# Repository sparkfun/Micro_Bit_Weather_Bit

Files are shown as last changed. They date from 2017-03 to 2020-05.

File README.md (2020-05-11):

SparkFun weather:bit - micro:bit Carrier Board (Qwiic)
========================================

SparkFun weather:bit (https://www.sparkfun.com/products/15837)

[*SparkFun weather:bit (DEV-15837)*](https://www.sparkfun.com/products/15837)

The SparkFun weather:bit is a fully loaded “carrier” board for the micro:bit that, when combined with the micro:bit, provides you with a fully functional weather station. With the weather:bit you will have access to barometric pressure, relative humidity and temperature readings. There are also connections on this carrier board to optional sensors such as wind speed, direction, rain gauge and soil readings! The micro:bit has a lot of features and a lot of potential for weather data collection.

Repository Contents
-------------------

* **/Firmware** -  Example code used in the micro:climate Kit Experiment Guide. While they are compiled HEX codes, you can modify the example code once they are imported into MakeCode editor.
* **/Hardware** - Eagle design files (.brd, .sch)
* **/Production** - Production panel files (.brd)

Documentation
--------------
* **[Library](https://github.com/sparkfun/pxt-weather-bit)** - PXT weather:bit firmware
* **[micro:Climate Kit Experiment Guide](https://learn.sparkfun.com/tutorials/microclimate-kit-experiment-guide)** - Experiment guide using the weather:bit carrier board.
* **[Wireless Remote Weather Station with micro:bit](https://learn.sparkfun.com/tutorials/wireless-remote-weather-station-with-microbit/)** - Additional experiments for transmitting weather data wirelessly.

License Information
-------------------

This product is _**open source**_! 

Please review the LICENSE.md file for license information. 

If you have any questions or concerns on licensing, please contact technical support on our [SparkFun forums](https://forum.sparkfun.com/viewforum.php?f=152).

Distributed as-is; no warranty is given.

- Your friends at SparkFun.

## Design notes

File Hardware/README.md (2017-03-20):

SparkFun <PRODUCT NAME> Design Files
=====================================

The .sch and .brd files hare are Eagle CAD schematic and PCB design files from SparkFun Electronics.
A freeware version of Eagle can be found [here](http://www.cadsoftusa.com/download-eagle/freeware/).

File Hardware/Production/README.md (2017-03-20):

SparkFun <PRODUCT NAME> Production Files
=========================================

These are the production files SparkFun uses for printing PCBs.

License Information
-------------------
This product is open source! 

The hardware is released under [Creative Commons ShareAlike 4.0 International](https://creativecommons.org/licenses/by-sa/4.0/).

Please use, reuse, and modify these files as you see fit. Please maintain attribution to SparkFun Electronics and release anything derivative under the same license.

Distributed as-is; no warranty is given.

- Your friends at SparkFun.

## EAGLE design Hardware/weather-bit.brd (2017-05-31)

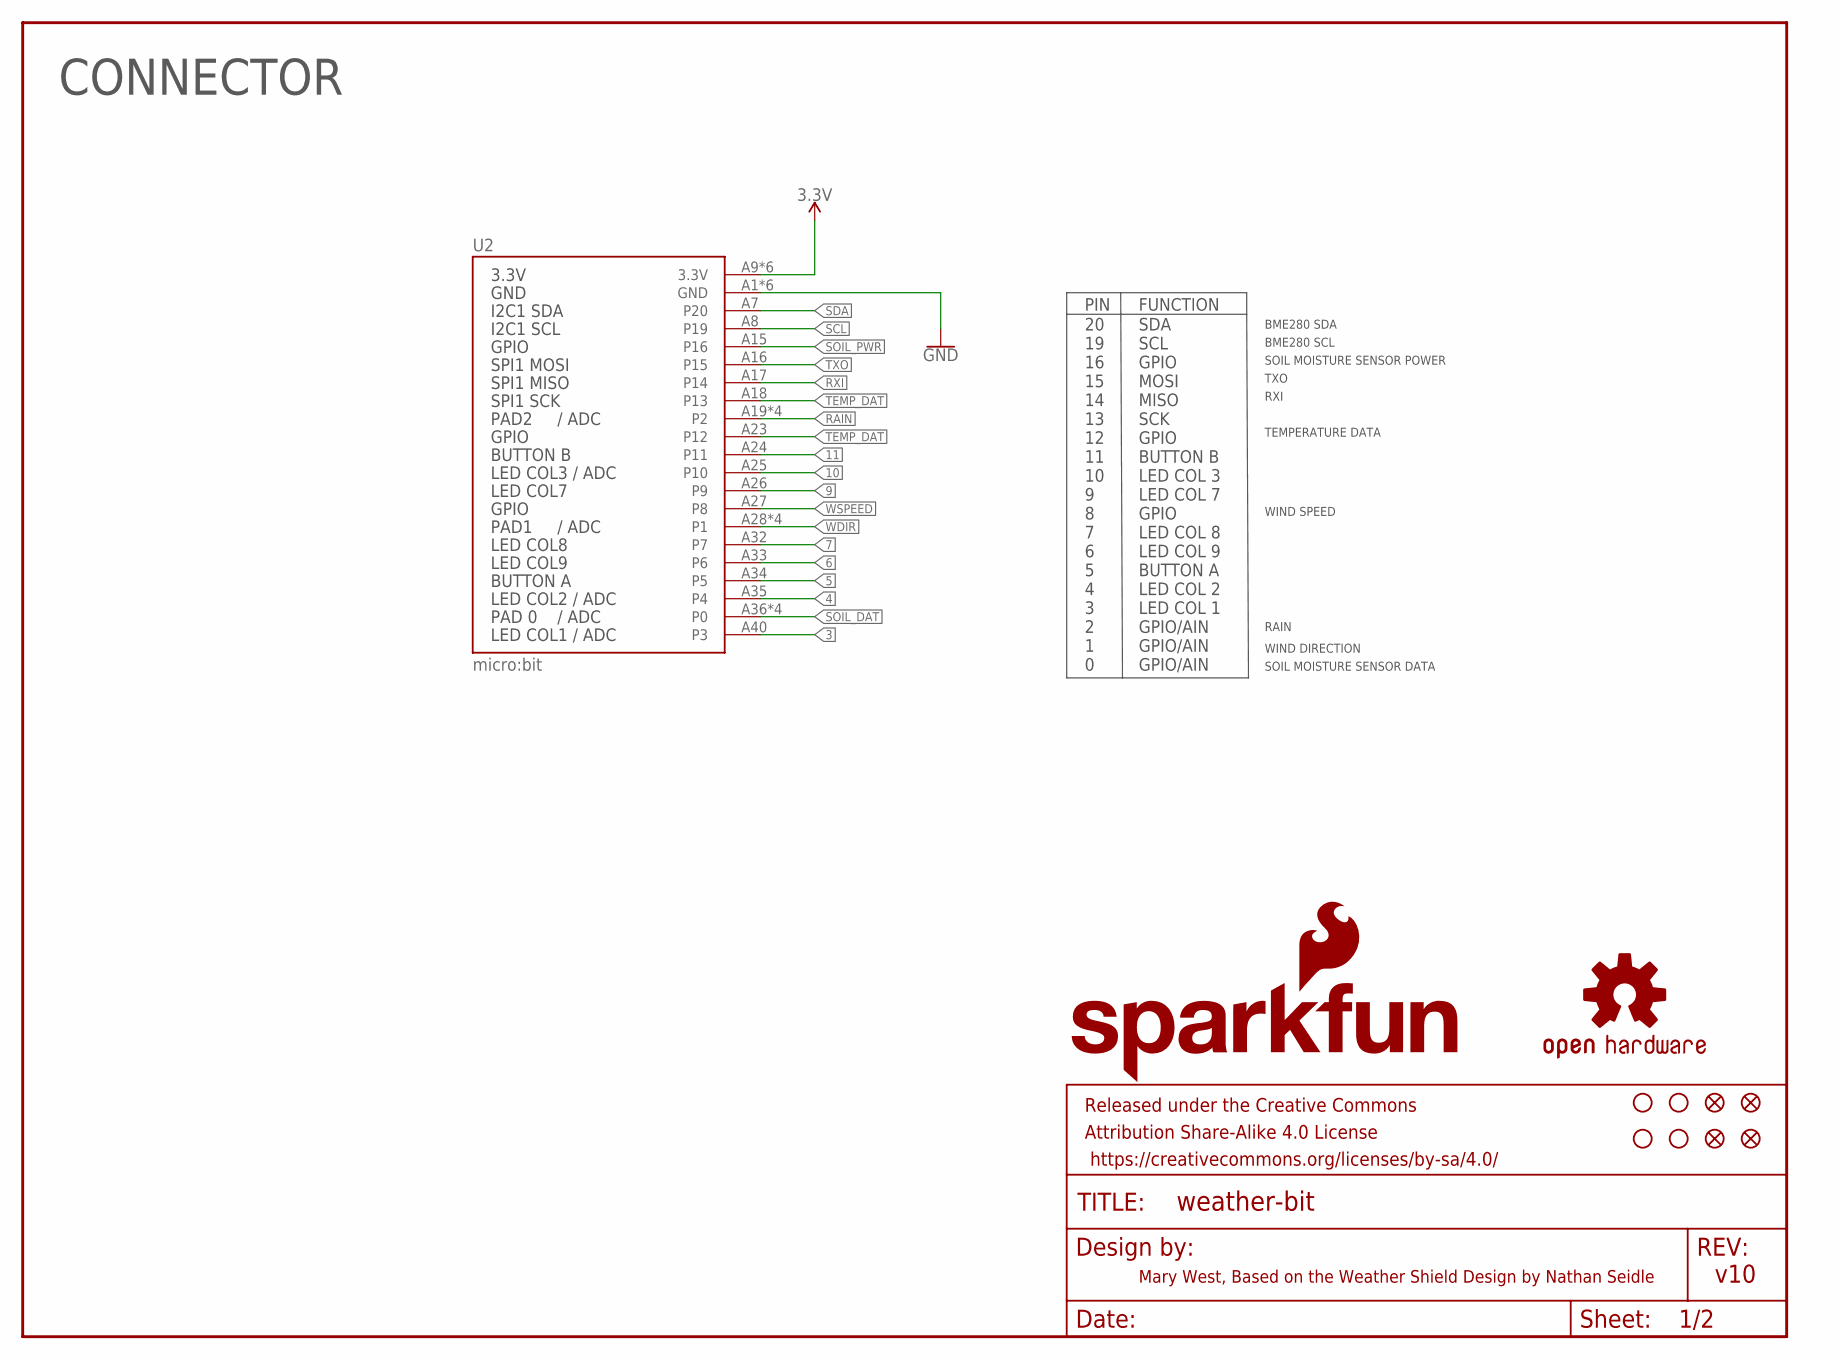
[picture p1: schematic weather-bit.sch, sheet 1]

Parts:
FD1, FD2, FD3, FD4: FIDUCIAL1X2; FIDUCIAL-1X2
FRAME1: FRAME-LETTER; CREATIVE_COMMONS
H1, H2, H3, H4: STAND-OFF
LOGO2: SFE_LOGO_NAME_FLAME.3_INCH; SFE_LOGO_NAME_FLAME_.3
LOGO3: OSHW-LOGOL; OSHW-LOGO-L
U2: micro:bit; MICRO:BIT_RA_PTH

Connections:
3: U2.A40 (P3)
3.3V: U2.A9 (3.3V), U2.A10 (3.3V), U2.A11 (3.3V), U2.A12 (3.3V), U2.A13 (3.3V), U2.A14 (3.3V); also elsewhere on the board
4: U2.A35 (P4)
5: U2.A34 (P5)
6: U2.A33 (P6)
7: U2.A32 (P7)
9: U2.A26 (P9)
10: U2.A25 (P10)
11: U2.A24 (P11)
GND: U2.A1 (GND), U2.A2 (GND), U2.A3 (GND), U2.A4 (GND), U2.A5 (GND), U2.A6 (GND); also elsewhere on the board
RAIN: U2.A19 (P2), U2.A20 (P2), U2.A21 (P2), U2.A22 (P2); also elsewhere on the board
RXI: U2.A17 (P14); also elsewhere on the board
SCL: U2.A8 (P19); also elsewhere on the board
SDA: U2.A7 (P20); also elsewhere on the board
SOIL_DAT: U2.A36 (P0), U2.A37 (P0), U2.A38 (P0), U2.A39 (P0); also elsewhere on the board
SOIL_PWR: U2.A15 (P16); also elsewhere on the board
TEMP_DAT: U2.A18 (P13), U2.A23 (P12); also elsewhere on the board
TXO: U2.A16 (P15); also elsewhere on the board
WDIR: U2.A28 (P1), U2.A29 (P1), U2.A30 (P1), U2.A31 (P1); also elsewhere on the board
WSPEED: U2.A27 (P8); also elsewhere on the board

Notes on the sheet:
v10
CONNECTOR
20 19 16 15 14 13 12 11 10 9 8 7 6 5 4 3 2 1 0
SDA SCL GPIO MOSI MISO SCK GPIO BUTTON B LED COL 3 LED COL 7 GPIO LED COL 8 LED COL 9 BUTTON A LED COL 2 LED COL 1 GPIO/AIN GPIO/AIN GPIO/AIN
PIN
FUNCTION
SOIL MOISTURE SENSOR DATA
BME280 SDA
BME280 SCL
SOIL MOISTURE SENSOR POWER
TEMPERATURE DATA
WIND DIRECTION
WIND SPEED
RAIN
TXO
RXI
Mary West, Based on the Weather Shield Design by Nathan Seidle

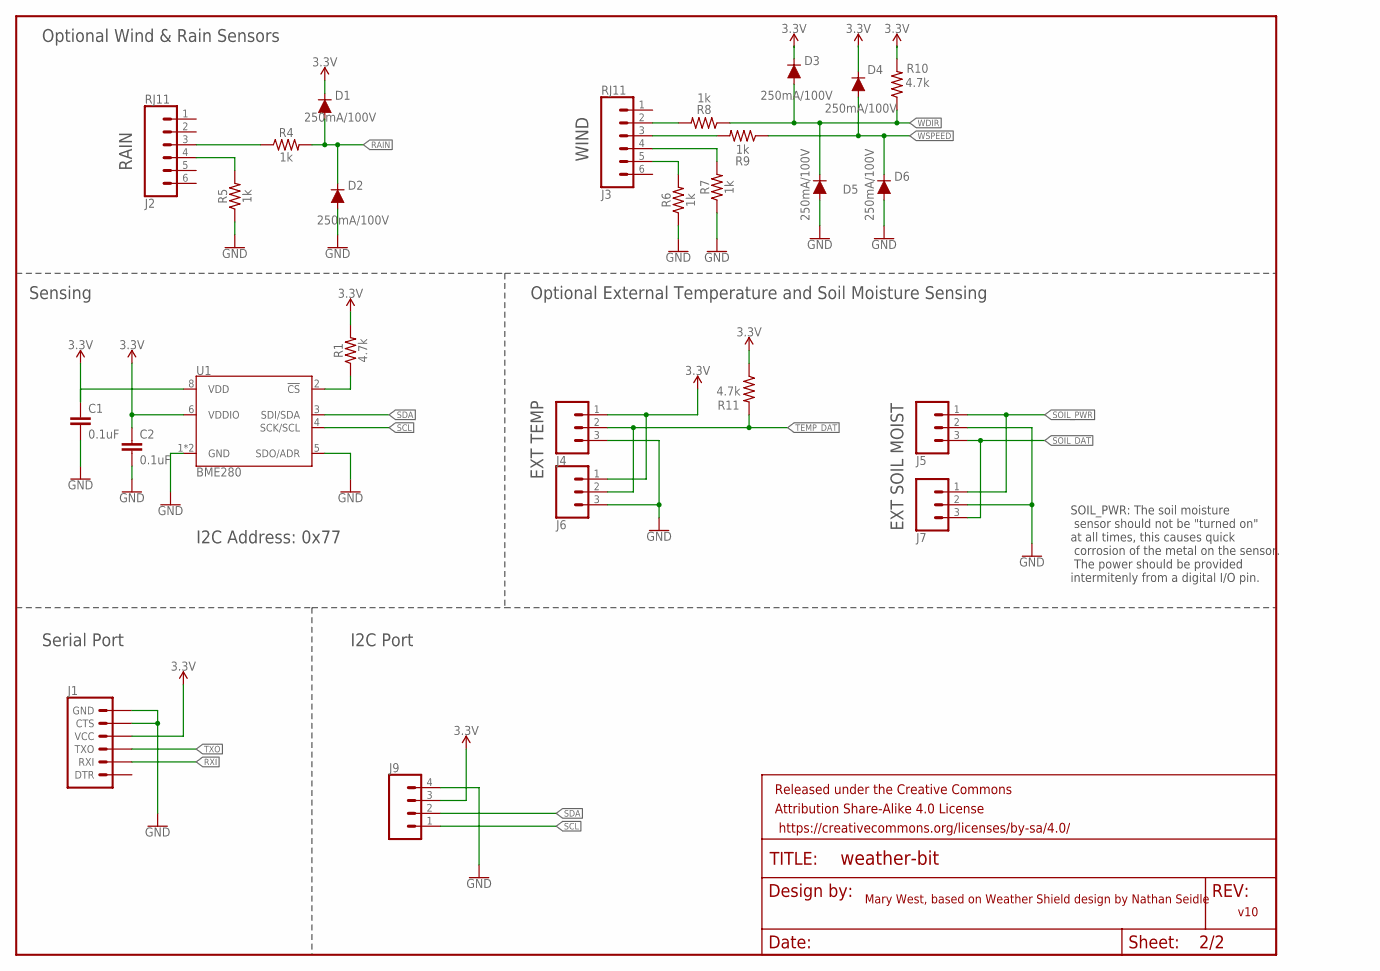
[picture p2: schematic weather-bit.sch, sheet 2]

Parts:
C1, C2: 0.1uF; 0603
D1, D2, D3, D4, D5, D6: 250mA/100V; SOD-323
FRAME2: FRAME-LETTER; CREATIVE_COMMONS
J1: 6_PIN_SERIAL_TARGETSILK; 6_PIN_SERIAL_TARGET_SIDE_W_SILK
J2, J3: RJ11; RJ11-6
J4, J5: CONN_03SCREW_LOCK; SCREWTERMINAL-3.5MM-3_LOCK.007S
J6, J7: CONN_03; 1X03
J9: CONN_041X04_NO_SILK; 1X04_NO_SILK
R1, R10, R11: 4.7k; 0603
R4, R5, R6, R7, R8, R9: 1k; 0603
U1: BME280; LGA-8-2.5X2.5

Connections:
3.3V: C1.1, C2.1, D1.C, D3.C, D4.C, J1.P$4 (VCC), J4.1, J6.1, J9.3, R1.2, R10.2, R11.1, U1.6 (VDDIO), U1.8 (VDD); also elsewhere on the board
GND: C1.2, C2.2, D2.A, D5.A, D6.A, J1.P$5 (CTS), J1.P$6 (GND), J4.3, J5.2, J6.3, J7.2, J9.4, R5.1, R6.1, R7.1, U1.1 (GND), U1.5 (SDO/ADR), U1.7 (GND); also elsewhere on the board
unnamed: R1.1, U1.2 (!CS)
unnamed: J2.3, R4.1
unnamed: J3.2, R8.2
unnamed: J2.4, R5.2
unnamed: J3.3, R9.2
unnamed: J3.5, R6.2
unnamed: J3.4, R7.2
RAIN: D1.A, D2.C, R4.2; also elsewhere on the board
RXI: J1.P$3 (RXI); also elsewhere on the board
SCL: J9.1, U1.4 (SCK/SCL); also elsewhere on the board
SDA: J9.2, U1.3 (SDI/SDA); also elsewhere on the board
SOIL_DAT: J5.3, J7.3; also elsewhere on the board
SOIL_PWR: J5.1, J7.1; also elsewhere on the board
TEMP_DAT: J4.2, J6.2, R11.2; also elsewhere on the board
TXO: J1.P$2 (TXO); also elsewhere on the board
WDIR: D3.A, D5.C, R8.1, R10.1; also elsewhere on the board
WSPEED: D4.A, D6.C, R9.1; also elsewhere on the board

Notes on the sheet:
I2C Address: 0x77
Sensing
RAIN
WIND
Optional Wind & Rain Sensors
Optional External Temperature and Soil Moisture Sensing
SOIL_PWR: The soil moisture sensor should not be "turned on" at all times, this causes quick corrosion of the metal on the sensor. The power should be provided intermitenly from a digital I/O pin.
EXT TEMP
EXT SOIL MOIST
Serial Port
I2C Port
Mary West, based on Weather Shield design by Nathan Seidle
v10

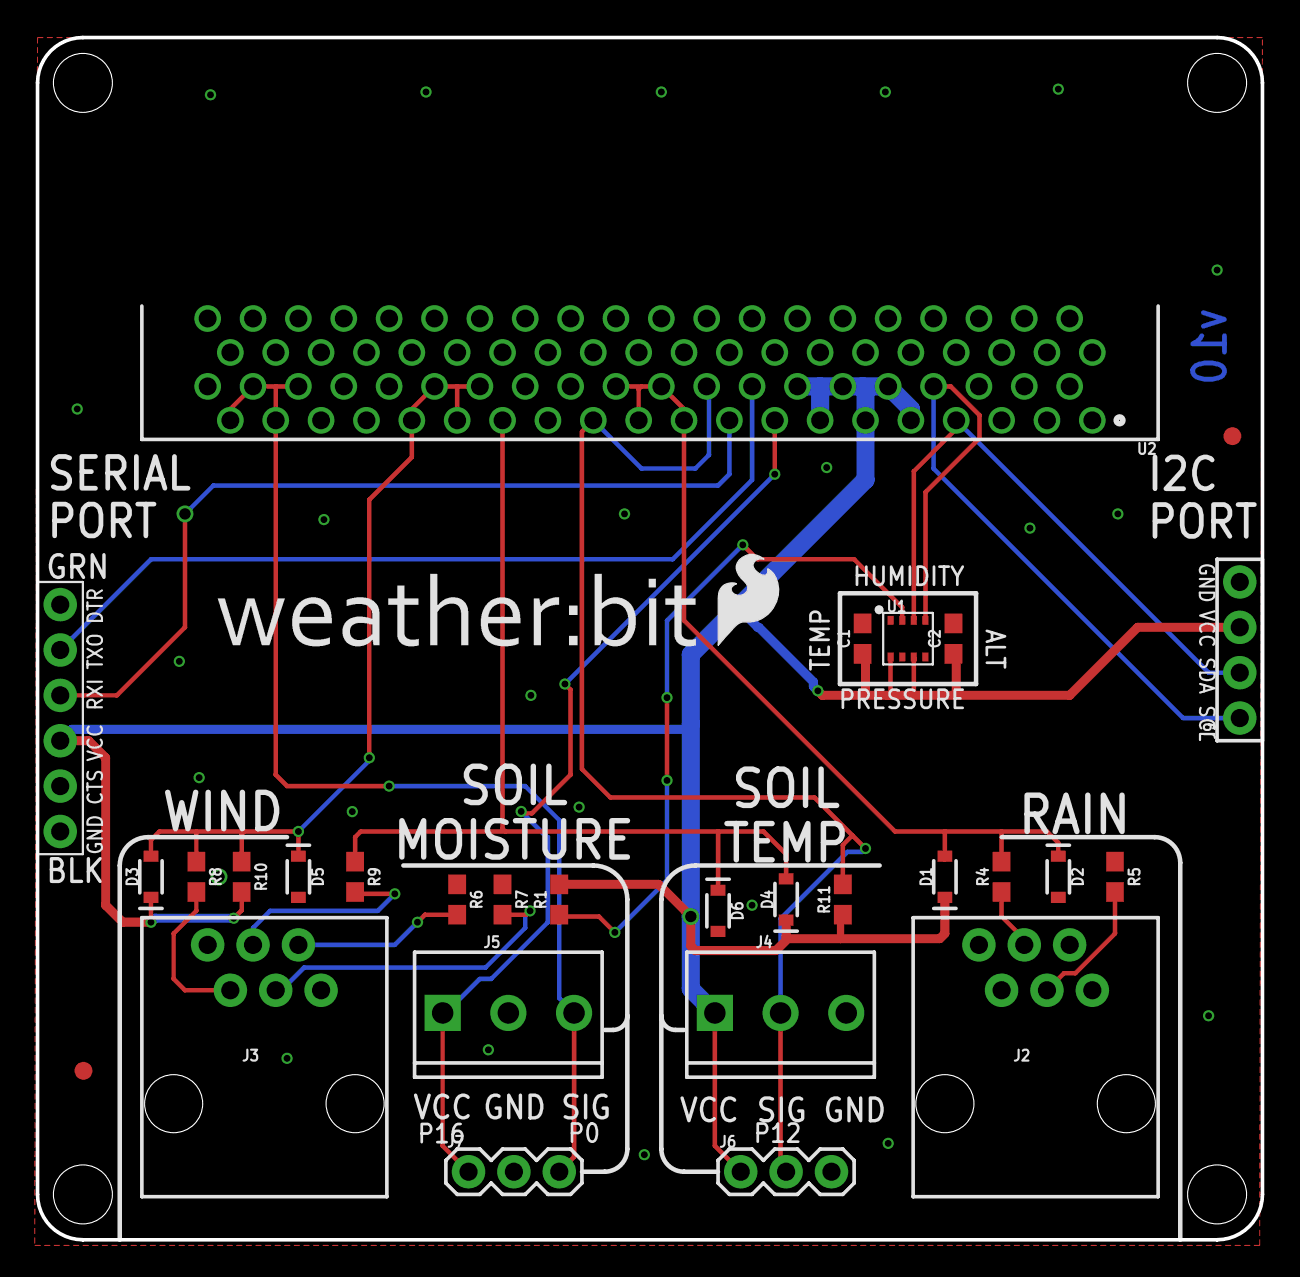
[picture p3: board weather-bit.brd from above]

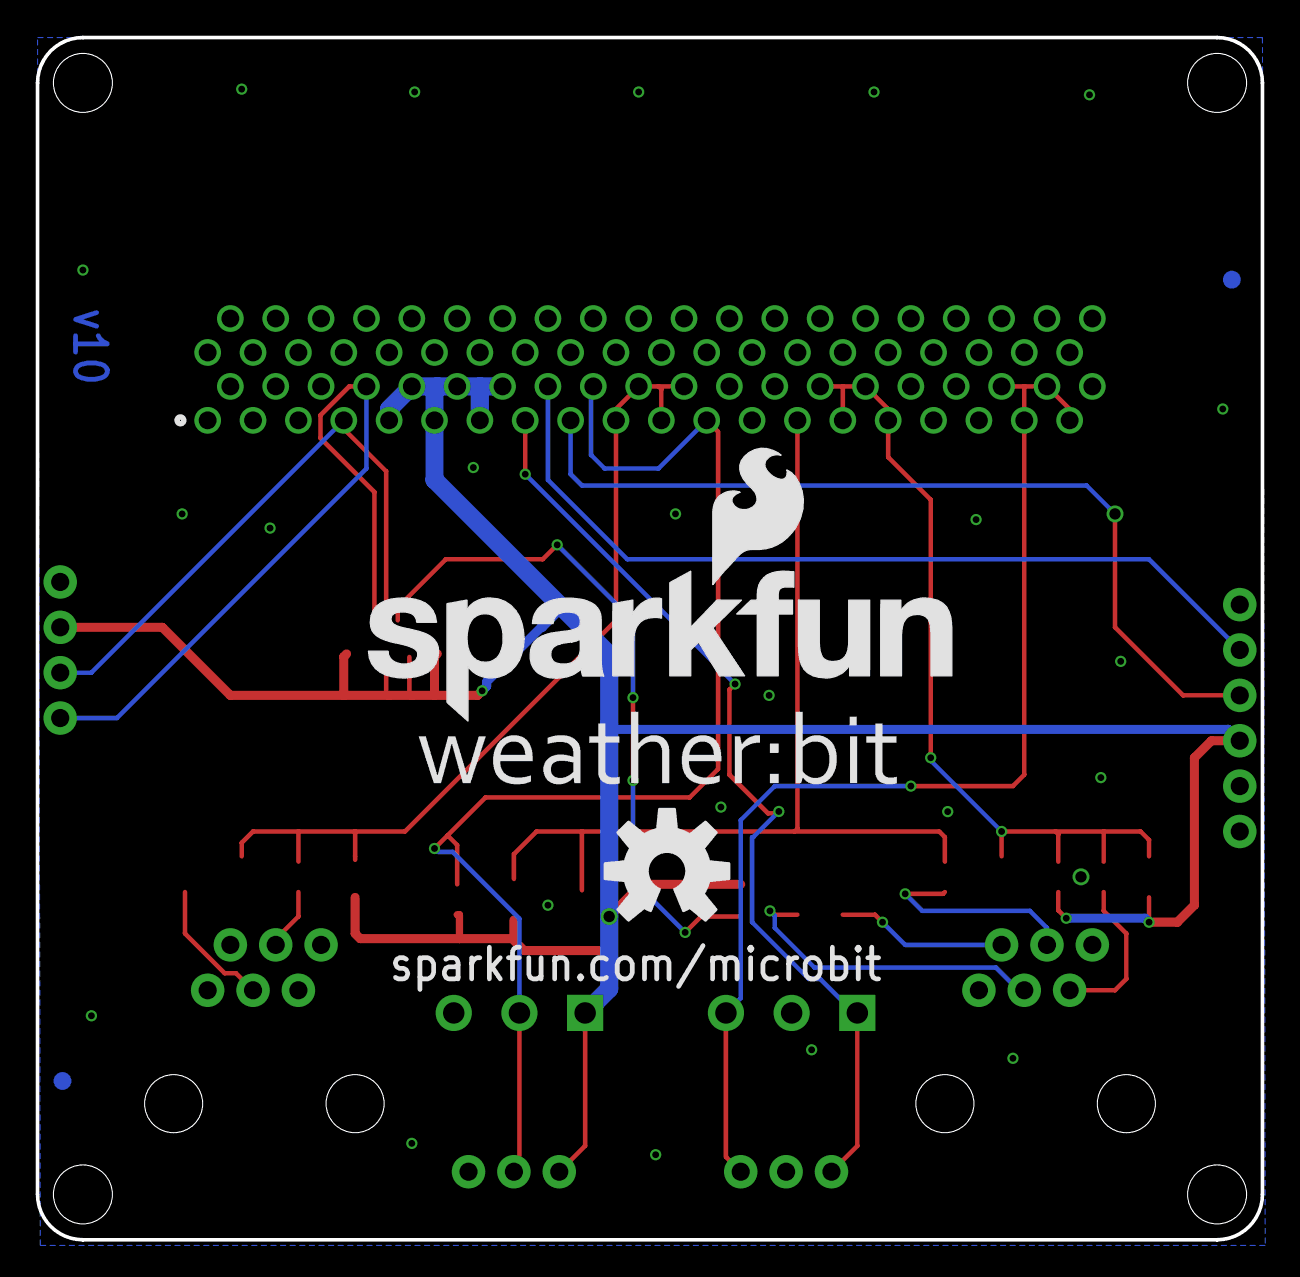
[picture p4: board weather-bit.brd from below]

Board: 2 copper layers, 68.6 x 67.3 mm, 43 parts (5 on the bottom side), 19 nets.

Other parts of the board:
U$1: SFE_LOGO_FLAME_.2
U$2, U$3: LOGO-WEATHERBIT
U$4: ORDERING_INSTRUCTIONS

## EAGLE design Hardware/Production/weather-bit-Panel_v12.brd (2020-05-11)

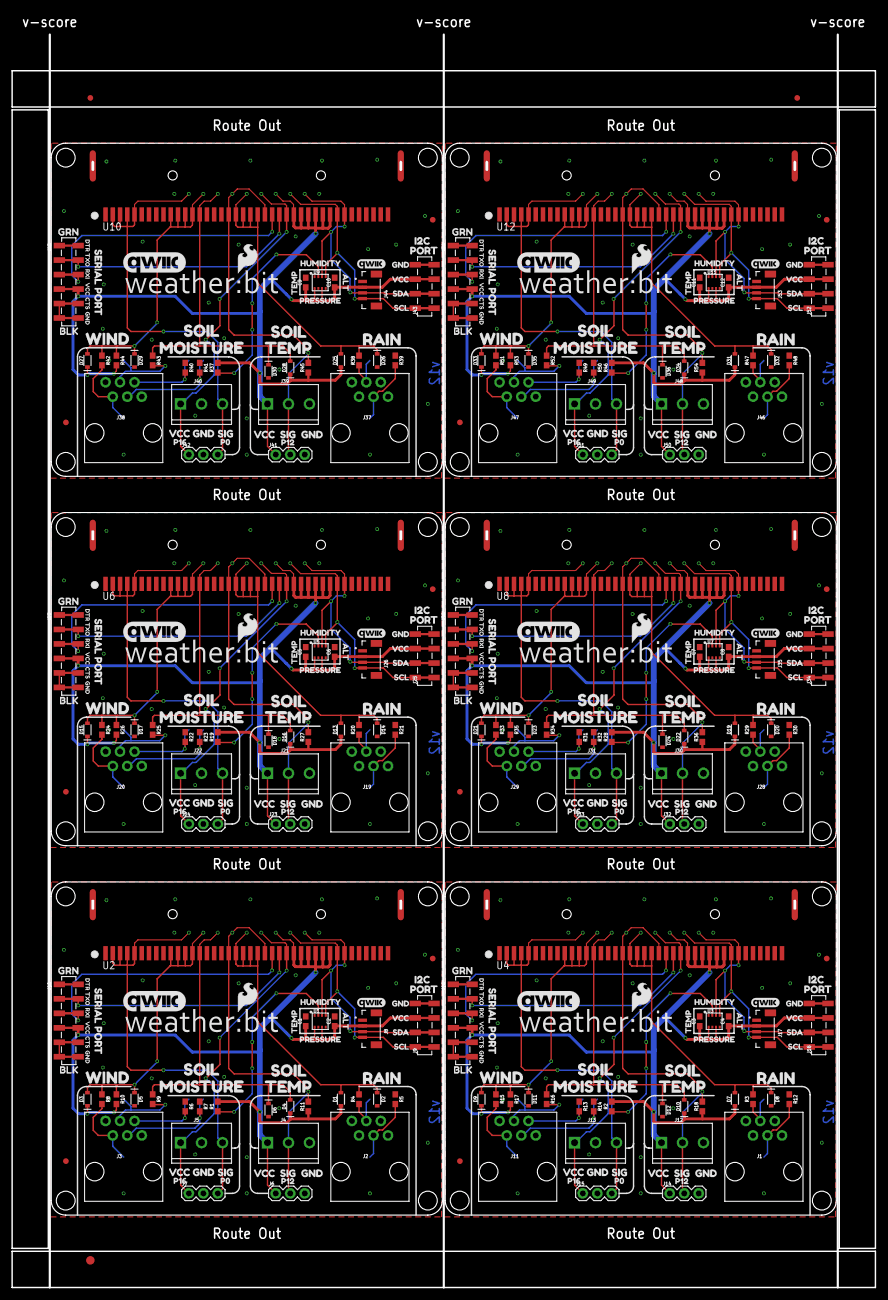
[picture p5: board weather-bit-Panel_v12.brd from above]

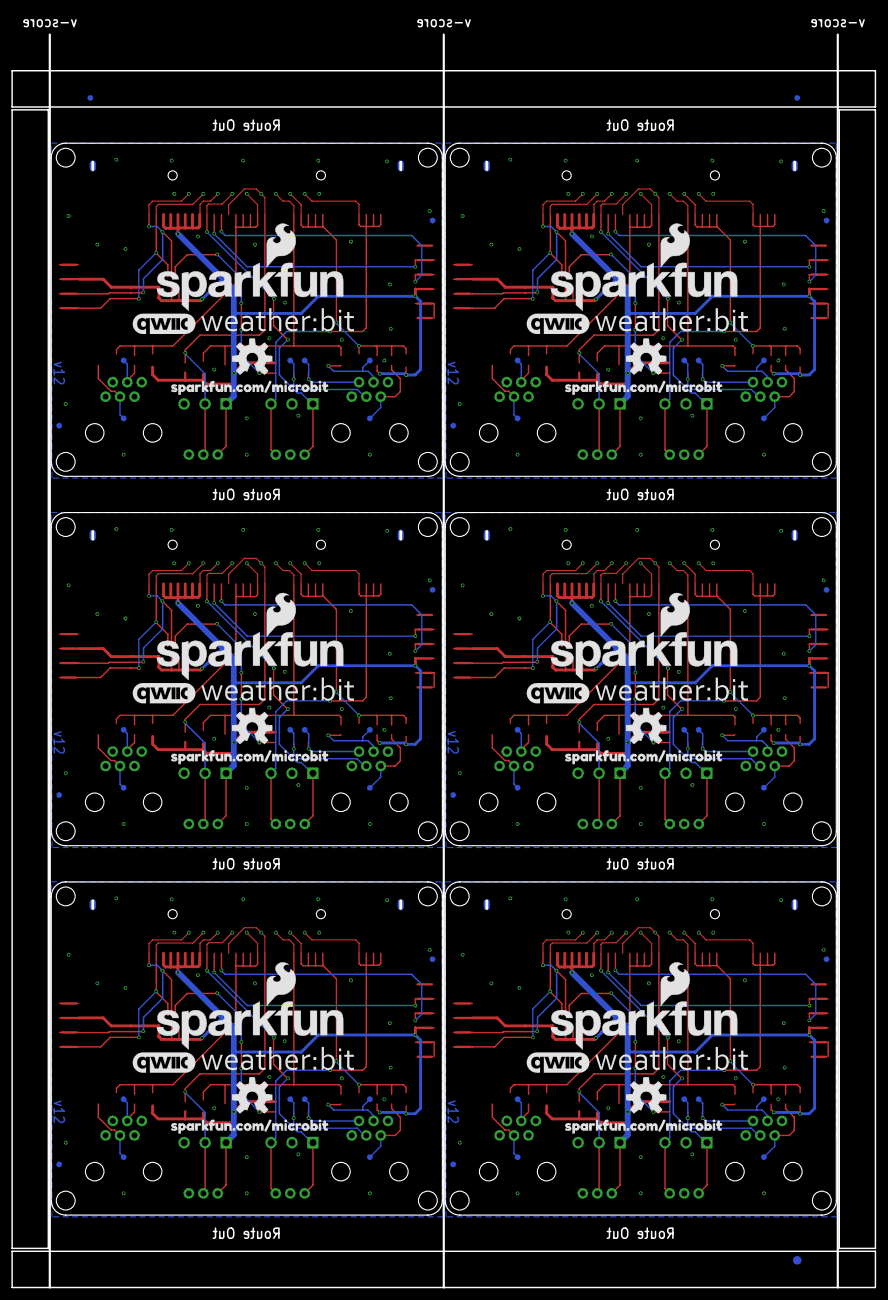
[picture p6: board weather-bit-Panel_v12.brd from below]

Board: 2 copper layers, 151.4 x 219.7 mm, 540 parts (81 on the bottom side), 114 nets.

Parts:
C1, C2, C3, C4, C5, C6, C7, C8, C9, C10, C11, C12: 0.1uF; 0603
D1, D2, D3, D4, D5, D6, D7, D8, D9, D10, D11, D12, D13, D14, D15, D16, D17, D18, D19, D20, D21, D22, D23, D24, D25, D26, D27, D28, D29, D30, D31, D32, D33, D34, D35, D36: 250mA/100V; SOD-323
E$1, E$2, E$3, E$4: FIDUCIAL-1X2
E$5, E$6: FIDUCIAL-1.5X3
FD1, FD2, FD3, FD4, FD5, FD6, FD7, FD8, FD9, FD10, FD11, FD12, FD13, FD14, FD15, FD16, FD17, FD18, FD19, FD20, FD21, FD22, FD23, FD24: FIDUCIAL1X2; FIDUCIAL-1X2
H1, H2, H3, H4, H5, H6, H7, H8, H9, H10, H11, H12, H13, H14, H15, H16, H17, H18, H19, H20, H21, H22, H23, H24: STAND-OFF
J1, J2, J3, J11, J19, J20, J28, J29, J37, J38, J46, J47: RJ11; RJ11-6
J4, J5, J12, J13, J21, J22, J30, J31, J39, J40, J48, J49: SCREWTERMINAL-3.5MM-3_LOCK.007S
J6, J7, J14, J15, J23, J24, J32, J33, J41, J42, J50, J51: 1X03
J8, J17, J26, J35, J44, J53: Qwiic (vertical); JST04_1MM_VERT
J9, J16, J25, J34, J43, J52: 1X04_SMD_STRAIGHT_COMBO; 1X04_SMD_VERTICAL_COMBO
J10, J18, J27, J36, J45, J54: SMD; 6_PIN_SERIAL_TARGET_SIDE_VERT_SMT
LOGO1, LOGO3, LOGO5, LOGO7, LOGO9, LOGO11: OSHW-LOGOL; OSHW-LOGO-L
LOGO2, LOGO4, LOGO6, LOGO8, LOGO10, LOGO12: SFE_LOGO_NAME_FLAME.3_INCH; SFE_LOGO_NAME_FLAME_.3
R1, R2, R10, R11, R17, R18, R19, R26, R27, R28, R35, R36, R37, R44, R45, R46, R53, R54: 4.7k; 0603
R3, R4, R5, R6, R7, R8, R9, R12, R13, R14, R15, R16, R20, R21, R22, R23, R24, R25, R29, R30, R31, R32, R33, R34, R38, R39, R40, R41, R42, R43, R47, R48, R49, R50, R51, R52: 1k; 0603
TP1, TP2, TP3, TP4, TP5, TP8, TP9, TP13, TP14, TP16, TP17, TP18, TP19, TP20, TP21, TP22, TP23, TP24, TP25, TP26, TP27, TP28, TP35, TP36, TP37, TP38, TP39, TP40, TP41, TP42, TP43, TP44, TP45, TP46, TP53, TP54, TP55, TP56, TP57, TP58, TP59, TP60, TP61, TP62, TP63, TP64, TP71, TP72, TP73, TP74, TP75, TP76, TP77, TP78, TP79, TP80, TP81, TP82, TP89, TP90, TP91, TP92, TP93, TP94, TP95, TP96, TP97, TP98, TP99, TP100, TP107, TP108: TP_15TH
TP6, TP7, TP10, TP11, TP12, TP15, TP29, TP30, TP31, TP32, TP33, TP34, TP47, TP48, TP49, TP50, TP51, TP52, TP65, TP66, TP67, TP68, TP69, TP70, TP83, TP84, TP85, TP86, TP87, TP88, TP101, TP102, TP103, TP104, TP105, TP106: PAD.03X.04
U1, U3, U5, U7, U9, U11: BME280; LGA-8-2.5X2.5
U2, U4, U6, U8, U10, U12: micro:bit; MICRO:BIT-RA_SMD
U$1, U$4, U$67, U$100, U$133, U$166: SFE_LOGO_FLAME_.2
U$2, U$3, U$35, U$36, U$68, U$69, U$101, U$102, U$134, U$135, U$167, U$168: LOGO-WEATHERBIT
U$5, U$37, U$70, U$103, U$136, U$169: QWIIC_5MM
U$6, U$7, U$38, U$39, U$71, U$72, U$104, U$105, U$137, U$138, U$170, U$171: QWIIC_11MM
U$8, U$40, U$73, U$106, U$139, U$172: I2C1
U$9, U$41, U$74, U$107, U$140, U$173: PORT2
U$10, U$42, U$75, U$108, U$141, U$174: SERIAL_PORT0
U$11, U$43, U$76, U$109, U$142, U$175: WIND12
U$12, U$13, U$44, U$45, U$77, U$78, U$110, U$111, U$143, U$144, U$176, U$177: SOIL13
U$14, U$46, U$79, U$112, U$145, U$178: MOISTURE14
U$15, U$47, U$80, U$113, U$146, U$179: TEMP15
U$16, U$48, U$81, U$114, U$147, U$180: RAIN16
U$17, U$21, U$49, U$53, U$82, U$86, U$115, U$119, U$148, U$152, U$181, U$185: VCC6
U$18, U$22, U$50, U$54, U$83, U$87, U$116, U$120, U$149, U$153, U$182, U$186: GND7
U$19, U$20, U$51, U$52, U$84, U$85, U$117, U$118, U$150, U$151, U$183, U$184: SIG8
U$23, U$55, U$88, U$121, U$154, U$187: P169
U$24, U$56, U$89, U$122, U$155, U$188: P010
U$25, U$57, U$90, U$123, U$156, U$189: P1211
U$26, U$58, U$91, U$124, U$157, U$190: HUMIDITY3
U$27, U$59, U$92, U$125, U$158, U$191: TEMP4
U$28, U$60, U$93, U$126, U$159, U$192: PRESSURE5
U$29, U$61, U$94, U$127, U$160, U$193: GND18
U$30, U$62, U$95, U$128, U$161, U$194: VCC19
U$31, U$63, U$96, U$129, U$162, U$195: SDA20
U$32, U$64, U$97, U$130, U$163, U$196: SCL21
U$33, U$65, U$98, U$131, U$164, U$197: SPARKFUN#COM#MICROBIT17
U$34, U$66, U$99, U$132, U$165, U$198: ALT0

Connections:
3.3V: C1.1, C2.1, D1.C, D3.C, D4.C, J4.1, J6.1, J8.2, J9.3, J9.3-2, J10.4, J10.4-2, R1.2, R10.2, R11.1, TP1.P$1, U1.6, U1.8, U2.P$27, U2.P$28, U2.P$29, U2.P$30, U2.P$31, U2.P$32
3.3V1: C3.1, C4.1, D7.C, D9.C, D10.C, J12.1, J14.1, J16.3, J16.3-2, J17.2, J18.4, J18.4-2, R2.2, R17.2, R18.1, TP18.P$1, U3.6, U3.8, U4.P$27, U4.P$28, U4.P$29, U4.P$30, U4.P$31, U4.P$32
3.3V2: C5.1, C6.1, D13.C, D15.C, D16.C, J21.1, J23.1, J25.3, J25.3-2, J26.2, J27.4, J27.4-2, R19.2, R26.2, R27.1, TP37.P$1, U5.6, U5.8, U6.P$27, U6.P$28, U6.P$29, U6.P$30, U6.P$31, U6.P$32
3.3V3: C7.1, C8.1, D19.C, D21.C, D22.C, J30.1, J32.1, J34.3, J34.3-2, J35.2, J36.4, J36.4-2, R28.2, R35.2, R36.1, TP55.P$1, U7.6, U7.8, U8.P$27, U8.P$28, U8.P$29, U8.P$30, U8.P$31, U8.P$32
3.3V4: C9.1, C10.1, D25.C, D27.C, D28.C, J39.1, J41.1, J43.3, J43.3-2, J44.2, J45.4, J45.4-2, R37.2, R44.2, R45.1, TP73.P$1, U9.6, U9.8, U10.P$27, U10.P$28, U10.P$29, U10.P$30, U10.P$31, U10.P$32
3.3V5: C11.1, C12.1, D31.C, D33.C, D34.C, J48.1, J50.1, J52.3, J52.3-2, J53.2, J54.4, J54.4-2, R46.2, R53.2, R54.1, TP91.P$1, U11.6, U11.8, U12.P$27, U12.P$28, U12.P$29, U12.P$30, U12.P$31, U12.P$32
GND: C1.2, C2.2, D2.A, D5.A, D6.A, J4.3, J5.2, J6.3, J7.2, J8.1, J9.4, J9.4-2, J10.5, J10.5-2, J10.6, J10.6-2, R5.1, R6.1, R7.1, TP2.P$1, TP16.P$1, TP17.P$1, U1.1, U1.5, U1.7, U2.P$35, U2.P$36, U2.P$37, U2.P$38, U2.P$39, U2.P$40
GND1: C3.2, C4.2, D8.A, D11.A, D12.A, J12.3, J13.2, J14.3, J15.2, J16.4, J16.4-2, J17.1, J18.5, J18.5-2, J18.6, J18.6-2, R12.1, R13.1, R14.1, TP20.P$1, TP35.P$1, TP36.P$1, U3.1, U3.5, U3.7, U4.P$35, U4.P$36, U4.P$37, U4.P$38, U4.P$39, U4.P$40
GND2: C5.2, C6.2, D14.A, D17.A, D18.A, J21.3, J22.2, J23.3, J24.2, J25.4, J25.4-2, J26.1, J27.5, J27.5-2, J27.6, J27.6-2, R21.1, R22.1, R23.1, TP38.P$1, TP53.P$1, TP54.P$1, U5.1, U5.5, U5.7, U6.P$35, U6.P$36, U6.P$37, U6.P$38, U6.P$39, U6.P$40
GND3: C7.2, C8.2, D20.A, D23.A, D24.A, J30.3, J31.2, J32.3, J33.2, J34.4, J34.4-2, J35.1, J36.5, J36.5-2, J36.6, J36.6-2, R30.1, R31.1, R32.1, TP56.P$1, TP71.P$1, TP72.P$1, U7.1, U7.5, U7.7, U8.P$35, U8.P$36, U8.P$37, U8.P$38, U8.P$39, U8.P$40
GND4: C9.2, C10.2, D26.A, D29.A, D30.A, J39.3, J40.2, J41.3, J42.2, J43.4, J43.4-2, J44.1, J45.5, J45.5-2, J45.6, J45.6-2, R39.1, R40.1, R41.1, TP74.P$1, TP89.P$1, TP90.P$1, U9.1, U9.5, U9.7, U10.P$35, U10.P$36, U10.P$37, U10.P$38, U10.P$39, U10.P$40
GND5: C11.2, C12.2, D32.A, D35.A, D36.A, J48.3, J49.2, J50.3, J51.2, J52.4, J52.4-2, J53.1, J54.5, J54.5-2, J54.6, J54.6-2, R48.1, R49.1, R50.1, TP92.P$1, TP107.P$1, TP108.P$1, U11.1, U11.5, U11.7, U12.P$35, U12.P$36, U12.P$37, U12.P$38, U12.P$39, U12.P$40
unnamed: R2.1, U3.2
unnamed: R1.1, U1.2
unnamed: R19.1, U5.2
unnamed: R28.1, U7.2
unnamed: R37.1, U9.2
unnamed: R46.1, U11.2
RAIN: D1.A, D2.C, R4.2, TP8.P$1, U2.P$19, U2.P$20, U2.P$21, U2.P$22
RAIN1: D7.A, D8.C, R3.2, TP24.P$1, U4.P$19, U4.P$20, U4.P$21, U4.P$22
RAIN2: D13.A, D14.C, R20.2, TP42.P$1, U6.P$19, U6.P$20, U6.P$21, U6.P$22
RAIN3: D19.A, D20.C, R29.2, TP60.P$1, U8.P$19, U8.P$20, U8.P$21, U8.P$22
RAIN4: D25.A, D26.C, R38.2, TP78.P$1, U10.P$19, U10.P$20, U10.P$21, U10.P$22
RAIN5: D31.A, D32.C, R47.2, TP96.P$1, U12.P$19, U12.P$20, U12.P$21, U12.P$22
RAIN_PIN_1: J1.3, R3.1, TP29.P$1
RAIN_PIN_2: J1.4, R12.2, TP30.P$1
RAIN_PIN_3: J2.3, R4.1, TP6.P$1
RAIN_PIN_4: J2.4, R5.2, TP7.P$1
RAIN_PIN_5: J19.3, R20.1, TP47.P$1
RAIN_PIN_6: J19.4, R21.2, TP48.P$1
RAIN_PIN_7: J28.3, R29.1, TP65.P$1
RAIN_PIN_8: J28.4, R30.2, TP66.P$1
RAIN_PIN_9: J37.3, R38.1, TP83.P$1
RAIN_PIN_10: J37.4, R39.2, TP84.P$1
RAIN_PIN_11: J46.3, R47.1, TP101.P$1
RAIN_PIN_12: J46.4, R48.2, TP102.P$1
RXI: J10.3, J10.3-2, U2.P$24
RXI1: J18.3, J18.3-2, U4.P$24
RXI2: J27.3, J27.3-2, U6.P$24
RXI3: J36.3, J36.3-2, U8.P$24
RXI4: J45.3, J45.3-2, U10.P$24
RXI5: J54.3, J54.3-2, U12.P$24
SCL: J8.4, J9.1, J9.1-2, TP4.P$1, U1.4, U2.P$33
SCL1: J16.1, J16.1-2, J17.4, TP22.P$1, U3.4, U4.P$33
SCL2: J25.1, J25.1-2, J26.4, TP40.P$1, U5.4, U6.P$33
SCL3: J34.1, J34.1-2, J35.4, TP58.P$1, U7.4, U8.P$33
SCL4: J43.1, J43.1-2, J44.4, TP76.P$1, U9.4, U10.P$33
SCL5: J52.1, J52.1-2, J53.4, TP94.P$1, U11.4, U12.P$33
SDA: J8.3, J9.2, J9.2-2, TP3.P$1, U1.3, U2.P$34
SDA1: J16.2, J16.2-2, J17.3, TP21.P$1, U3.3, U4.P$34
SDA2: J25.2, J25.2-2, J26.3, TP39.P$1, U5.3, U6.P$34
SDA3: J34.2, J34.2-2, J35.3, TP57.P$1, U7.3, U8.P$34
SDA4: J43.2, J43.2-2, J44.3, TP75.P$1, U9.3, U10.P$34
SDA5: J52.2, J52.2-2, J53.3, TP93.P$1, U11.3, U12.P$34
SOIL_DAT: J5.3, J7.3, TP19.P$1, U2.P$2, U2.P$3, U2.P$4, U2.P$5
SOIL_DAT1: J13.3, J15.3, TP28.P$1, U4.P$2, U4.P$3, U4.P$4, U4.P$5
SOIL_DAT2: J22.3, J24.3, TP46.P$1, U6.P$2, U6.P$3, U6.P$4, U6.P$5
SOIL_DAT3: J31.3, J33.3, TP64.P$1, U8.P$2, U8.P$3, U8.P$4, U8.P$5
SOIL_DAT4: J40.3, J42.3, TP82.P$1, U10.P$2, U10.P$3, U10.P$4, U10.P$5
SOIL_DAT5: J49.3, J51.3, TP100.P$1, U12.P$2, U12.P$3, U12.P$4, U12.P$5
SOIL_PWR: J5.1, J7.1, TP5.P$1, U2.P$26
SOIL_PWR1: J13.1, J15.1, TP23.P$1, U4.P$26
SOIL_PWR2: J22.1, J24.1, TP41.P$1, U6.P$26
SOIL_PWR3: J31.1, J33.1, TP59.P$1, U8.P$26
SOIL_PWR4: J40.1, J42.1, TP77.P$1, U10.P$26
SOIL_PWR5: J49.1, J51.1, TP95.P$1, U12.P$26
TEMP_DAT: J4.2, J6.2, R11.2, TP9.P$1, U2.P$18, U2.P$23
TEMP_DAT1: J12.2, J14.2, R18.2, TP25.P$1, U4.P$18, U4.P$23
TEMP_DAT2: J21.2, J23.2, R27.2, TP43.P$1, U6.P$18, U6.P$23
TEMP_DAT3: J30.2, J32.2, R36.2, TP61.P$1, U8.P$18, U8.P$23
TEMP_DAT4: J39.2, J41.2, R45.2, TP79.P$1, U10.P$18, U10.P$23
TEMP_DAT5: J48.2, J50.2, R54.2, TP97.P$1, U12.P$18, U12.P$23
TXO: J10.2, J10.2-2, U2.P$25
TXO1: J18.2, J18.2-2, U4.P$25
TXO2: J27.2, J27.2-2, U6.P$25
TXO3: J36.2, J36.2-2, U8.P$25
TXO4: J45.2, J45.2-2, U10.P$25
TXO5: J54.2, J54.2-2, U12.P$25
WDIR: D3.A, D5.C, R8.1, R10.1, TP14.P$1, U2.P$10, U2.P$11, U2.P$12, U2.P$13
WDIR1: D9.A, D11.C, R15.1, R17.1, TP27.P$1, U4.P$10, U4.P$11, U4.P$12, U4.P$13
WDIR2: D15.A, D17.C, R24.1, R26.1, TP45.P$1, U6.P$10, U6.P$11, U6.P$12, U6.P$13
WDIR3: D21.A, D23.C, R33.1, R35.1, TP63.P$1, U8.P$10, U8.P$11, U8.P$12, U8.P$13
WDIR4: D27.A, D29.C, R42.1, R44.1, TP81.P$1, U10.P$10, U10.P$11, U10.P$12, U10.P$13
WDIR5: D33.A, D35.C, R51.1, R53.1, TP99.P$1, U12.P$10, U12.P$11, U12.P$12, U12.P$13
WIND_PIN_1: J11.3, R16.2, TP32.P$1
WIND_PIN_2: J3.2, R8.2, TP10.P$1
WIND_PIN_3: J3.3, R9.2, TP11.P$1
WIND_PIN_4: J3.4, R7.2, TP12.P$1
WIND_PIN_5: J3.5, R6.2, TP15.P$1
WIND_PIN_6: J11.5, R13.2, TP34.P$1
WIND_PIN_7: J11.4, R14.2, TP33.P$1
WIND_PIN_8: J11.2, R15.2, TP31.P$1
WIND_PIN_9: J20.3, R25.2, TP50.P$1
WIND_PIN_10: J20.5, R22.2, TP52.P$1
WIND_PIN_11: J20.4, R23.2, TP51.P$1
WIND_PIN_12: J20.2, R24.2, TP49.P$1
WIND_PIN_13: J29.3, R34.2, TP68.P$1
WIND_PIN_14: J29.5, R31.2, TP70.P$1
WIND_PIN_15: J29.4, R32.2, TP69.P$1
WIND_PIN_16: J29.2, R33.2, TP67.P$1
WIND_PIN_17: J38.3, R43.2, TP86.P$1
WIND_PIN_18: J38.5, R40.2, TP88.P$1
WIND_PIN_19: J38.4, R41.2, TP87.P$1
WIND_PIN_20: J38.2, R42.2, TP85.P$1
WIND_PIN_21: J47.3, R52.2, TP104.P$1
WIND_PIN_22: J47.5, R49.2, TP106.P$1
WIND_PIN_23: J47.4, R50.2, TP105.P$1
WIND_PIN_24: J47.2, R51.2, TP103.P$1
WSPEED: D4.A, D6.C, R9.1, TP13.P$1, U2.P$14
WSPEED1: D10.A, D12.C, R16.1, TP26.P$1, U4.P$14
WSPEED2: D16.A, D18.C, R25.1, TP44.P$1, U6.P$14
WSPEED3: D22.A, D24.C, R34.1, TP62.P$1, U8.P$14
WSPEED4: D28.A, D30.C, R43.1, TP80.P$1, U10.P$14
WSPEED5: D34.A, D36.C, R52.1, TP98.P$1, U12.P$14

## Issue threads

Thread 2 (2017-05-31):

double check for v10

edspark, 2017-05-31:
None of the changes I made yesterday got pushed up. I'm not sure why. On my home machine it says it was pushed. I've updated 1, 2, 4, and 5. The TX/RX lines are programmable in microbit. So it doesn't matter. There isn't a set I/O for those.

Sorry that you went through the checklist on old junk.

1) Is the version number correct? [NO]
comment: Needs to be changed to v10

2) Is the version number included on all sheets? [NO]
comment: Make sure to change revision on both pages

3) Are the TX/RX pins of the FTDI properly connected? [NO]
comment: I'm confused are the MOSI/MISO pins being used for TX/RX? If so have you confirmed that the polarity of the RX/TX lines are correct?

4) Is there a correct version number in the copper (aligned properly with the edge of the PCB)? [NO]
comment: Needs to be changed to v10

An airwire, you'll notice that the topside 3.3V line going into the resistor didn't quite make it all the way:

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

ToniCorinne, 2017-08-14:
@ADataDate can this issue be closed out? I'm assuming this was all addressed for the live version of the board.

Closed 2017-08-14.

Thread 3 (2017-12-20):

weatherproof?

nielsswinkels, 2017-12-20:
I can't imagine this thing to be able to survive outdoor conditions. What would be the best strategy to measure outdoor humidity with this?

On a side note I was wondering it if has any max & min temperatures it can handle?

ADataDate, 2017-12-20:
The temp range is -40C to 85C.

I've actually seen some pretty inventive solutions for weatherproofing: https://twitter.com/thenerdyteacher/status/893254979515015168. This will, of course, skew temperature data but that is why the weatherproof DS18B20 Temp sensor connection port and makecode package is also available.

I've also seen people take it to the beach screwed onto a pole stuck in the ground. I think your solution will depend on your environment.

The weather:bit can also be placed in a project enclosure like the [Big Red Box](https://www.sparkfun.com/products/11366). Holes can be drilled for the weather meters and external temp sensor then sealed with epoxy or even hot glue. The [BME280](https://www.bosch-sensortec.com/bst/products/all_products/bme280) is meant to be put into an enclosure for wearable devices and such. So,  some experiments will probably need to be conducted to work with off-sets and get it properly calibrated.

Closed 2018-07-06.

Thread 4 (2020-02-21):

Is it possible to directly access this under yt / cpp?

kwccoin, 2020-02-21:
I have successfully use this using the block/js plus serial output.  Thanks. It is a great learning environment.

Is it possible to compile this with my own code for BLE under yt / mbed environment?

TL;DR:

As a more mature project I would like to move to BLE, instead of moving to another weather board.

But the initial part found it is hard as not sure what is going on.  I suspect it might be due to some device limitation (memory etc. got some error code over the bitcode led). I wonder whether I can escape this student mode to more familiar mode of c++.  And wonder whether any chance of debug over this environment especially how to check on any memory issue.

But before I ticket this possibility to tickle the limit of the mix of ble + weather:bit, I wonder any chance to do this at all.  (I note another module using ble and cpp cannot be run even for some xmas LED / song also encounter problem with the new BLE memory.  Wonder.  May be only serial not radio/ble ...

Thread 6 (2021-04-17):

Compilation issue for GatorRTC

bmurphy-dev, 2021-04-17:
This problem exists in MakeCode Blocks, JS, and Python editors. Project will not compile properly for the Gator RTC wireless data logging experiment.
Receiving wireless data Wireless Weather Data Experiment 5.2: https://github.com/sparkfun/Micro_Bit_Weather_Bit/blob/master/Firmware/Wireless_Remote_Weather_Station/microbit-52-RTC-Weather-Station-Request-Receive-Data-Check-Deb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
SparkFun Forum Thread: https://forum.sparkfun.com/viewtopic.php?uid=73026&f=88&t=55021&start=0

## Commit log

2017-03-23 Sch and Brd files initial commit
    [weather-bit.brd, weather-bit.sch]
2017-03-27 Updated Baord Layout, prepping for today's meeting
    [weather-bit.brd]
2017-03-29 Updated brd and sch file 3/28/2017
    [weather-bit.brd, weather-bit.sch]
2017-03-29 updated board and sch files 3/29
    [weather-bit.brd, weather-bit.sch]
2017-03-30 Adding Library Part Updated Brd File Updated Sch File 3/30/2017
    [weather-bit.brd, weather-bit.sch]
2017-04-03 Updated BRD and SCH files per Design Review 3/31
    [weather-bit.brd, weather-bit.sch]
2017-04-06 Updated brd and sch files per QC Review
    [weather-bit.brd, weather-bit.sch]
2017-04-10 Updated BRD and SCH files per EDU
    [weather-bit.brd, weather-bit.sch]
2017-04-11 replacing proportional font back to vector font
    [weather-bit.brd, weather-bit.sch]
2017-04-18 updated weather:bit Logo
    [weather-bit.brd]
2017-04-18 Updated logo info
    [weather-bit.brd]
2017-04-20 Updated silk per review 4/19
    [weather-bit.brd]
2017-05-23 Updated One-Wire Hardware Set-up
    [weather-bit.brd, weather-bit.sch]
2017-05-31 Updating weather:bit per QC review
    [weather-bit.brd, weather-bit.sch]
2017-05-31 Updated text in sch
    [weather-bit.sch]
2019-02-08 Update microbit-Weather-Bit-Experiment-7-OpenLog.hex
    Updated code with button press to begin logging and to pause logging. It's a hex file but you can still import it in MakeCode to view code.
2019-02-08 Update microbit-Weather-Bit-Experiment-7-OpenLog.hex
    Update code again for a better user experience. There was a weird debounce after pressing the button the first time. =)
2019-10-30 Added qwiic connector and logos
    - added vertical qwiic connector near the 4-pin I2C header
    - added qwiic logo near connector
    - added big qwiic logos near product names on top and bottom silk
    [weather-bit.brd, weather-bit.sch]
2019-10-30 SMD connector on 40 pin RA, and 4-pin I2C header
    [weather-bit.brd, weather-bit.sch]
2019-10-31 Moved to SMT vertical female header for Serial port
    [weather-bit.brd, weather-bit.sch]
2019-10-31 SMT serial header and buzzard silk update
    [weather-bit.brd, weather-bit.sch]
2019-10-31 sch cleanup and move to one sheet
    [weather-bit.brd, weather-bit.sch]
2019-10-31 PROD_ID on serial header SMT vertical
    [weather-bit.brd, weather-bit.sch]
2019-10-31 run of checklist
    - vector font in sch
    - added testpoints
    - corrected measures
    [weather-bit.brd, weather-bit.sch]
2019-11-04 switched to TIGHT DRC, nudging and routing
    -updated package on 4-pin SMD to allow for routing to either pad under each header
    -moved to TIGHT DRC, some slight nudging of routes to comply
    -rotated SERIAL PORT silk to match pin labels
    [weather-bit.brd, weather-bit.sch]
2019-11-05 Finalized test points and test point positions
    [weather-bit.brd, weather-bit.sch]
2019-11-05 gerbers for proto order
2019-12-10 Connected TEMP_DATA to P13
    On v10, TEMP_DATA was connected to both P12 and P13 (for the one-wire interface to the temp sensor).
    v11 only had TEMP_DATA connected to P12.
    With this commit (v12), TEMP_DATA is connected to both P12 and P13 (to match the original v10).
    Also incremented version to v12 in BRD and SCH.
    [weather-bit.brd, weather-bit.sch]
2019-12-13 Production panel v12
    [13660_weather-bit-panel.v10.brd, weather-bit-Panel_v12.brd]
2020-02-03 Update for MakeCode V1
    MakeCode Editor v1 does floating point arithmetic now and will output several decimal places on the LED display. Updated examples to prevent user from waiting until the data finishes scrolling.
    - update exp 1 to simply output integer using integer division block
    - update exp 4 to simply output integer using integer division block
    - update exp 5 to truncate the output to output integer with the option to view the output on the MakeCode Console
    - update exp 6 animation to read easier, round the output, and option to view data on the MakeCode Console
2020-05-11 Add Wireless Examples

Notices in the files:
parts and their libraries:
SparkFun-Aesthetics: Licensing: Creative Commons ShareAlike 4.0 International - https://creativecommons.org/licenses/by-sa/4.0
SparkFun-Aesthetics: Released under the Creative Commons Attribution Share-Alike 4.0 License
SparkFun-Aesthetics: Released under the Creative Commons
